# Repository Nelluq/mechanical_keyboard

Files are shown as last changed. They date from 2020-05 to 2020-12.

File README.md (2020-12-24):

# Mechanical Keyboard

## Background and Overview
This is a simple exposed-PCB design for a Cherry MX-based mechanical keyboard. It is a full-size 104-key board, but also
includes 4 extra keys that can be used for anything. It uses PCB-mount Cherry MX switches, and can be assembled with any
color non-backlit switch (I don't care for keyboard backlighting, so I didn't include it). It runs on an STM32F070C6
microcontroller.

The PCB was designed in [KiCad](https://kicad-pcb.org), which conveniently already had Cherry MX key switches in its
component libraries. Except for the key switches and the USB port, all the components are surface mount. This can make
it a little trickier to hand solder for people with less soldering experience (especially the 108 SOD-323 diodes...),
but it's entirely possible.

I started the project in August 2019 because I needed a better keyboard for work. I also wanted to try out STM32 MCUs,
which I hadn't used before. I couldn't get the firmware working initially, so set it aside for a few months and finally
finished it in February 2020. The first version of the firmware was written using the STM32Cube framework with
STM32 HAL, but I ended up not being satisfied with the generated code from that system, and the keyboard itself wasn't
working as well as I wanted. Eventually, in April 2020, I rewrote the entirity of the firmware using
[libopencm3](https://gitub.com/libopencm3/libopencm3), which is vastly cleaner and nicer to work with than ST's own
framework.

## Example
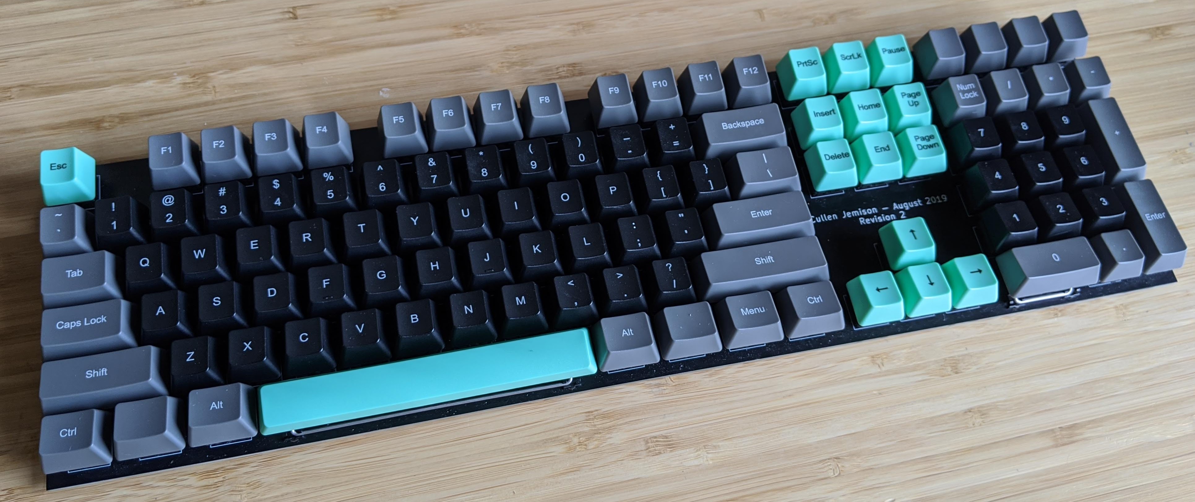
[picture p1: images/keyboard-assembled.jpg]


This is my keyboard, built on the Rev 2 PCB (newer PCB versions are slightly improved, but generally the same). I used
Cherry MX brown switches (I prefer blues, but I wanted this to be quieter for work) and opted for matte black
soldermask, which I think looks awesome.

## Instructions
Coming soon

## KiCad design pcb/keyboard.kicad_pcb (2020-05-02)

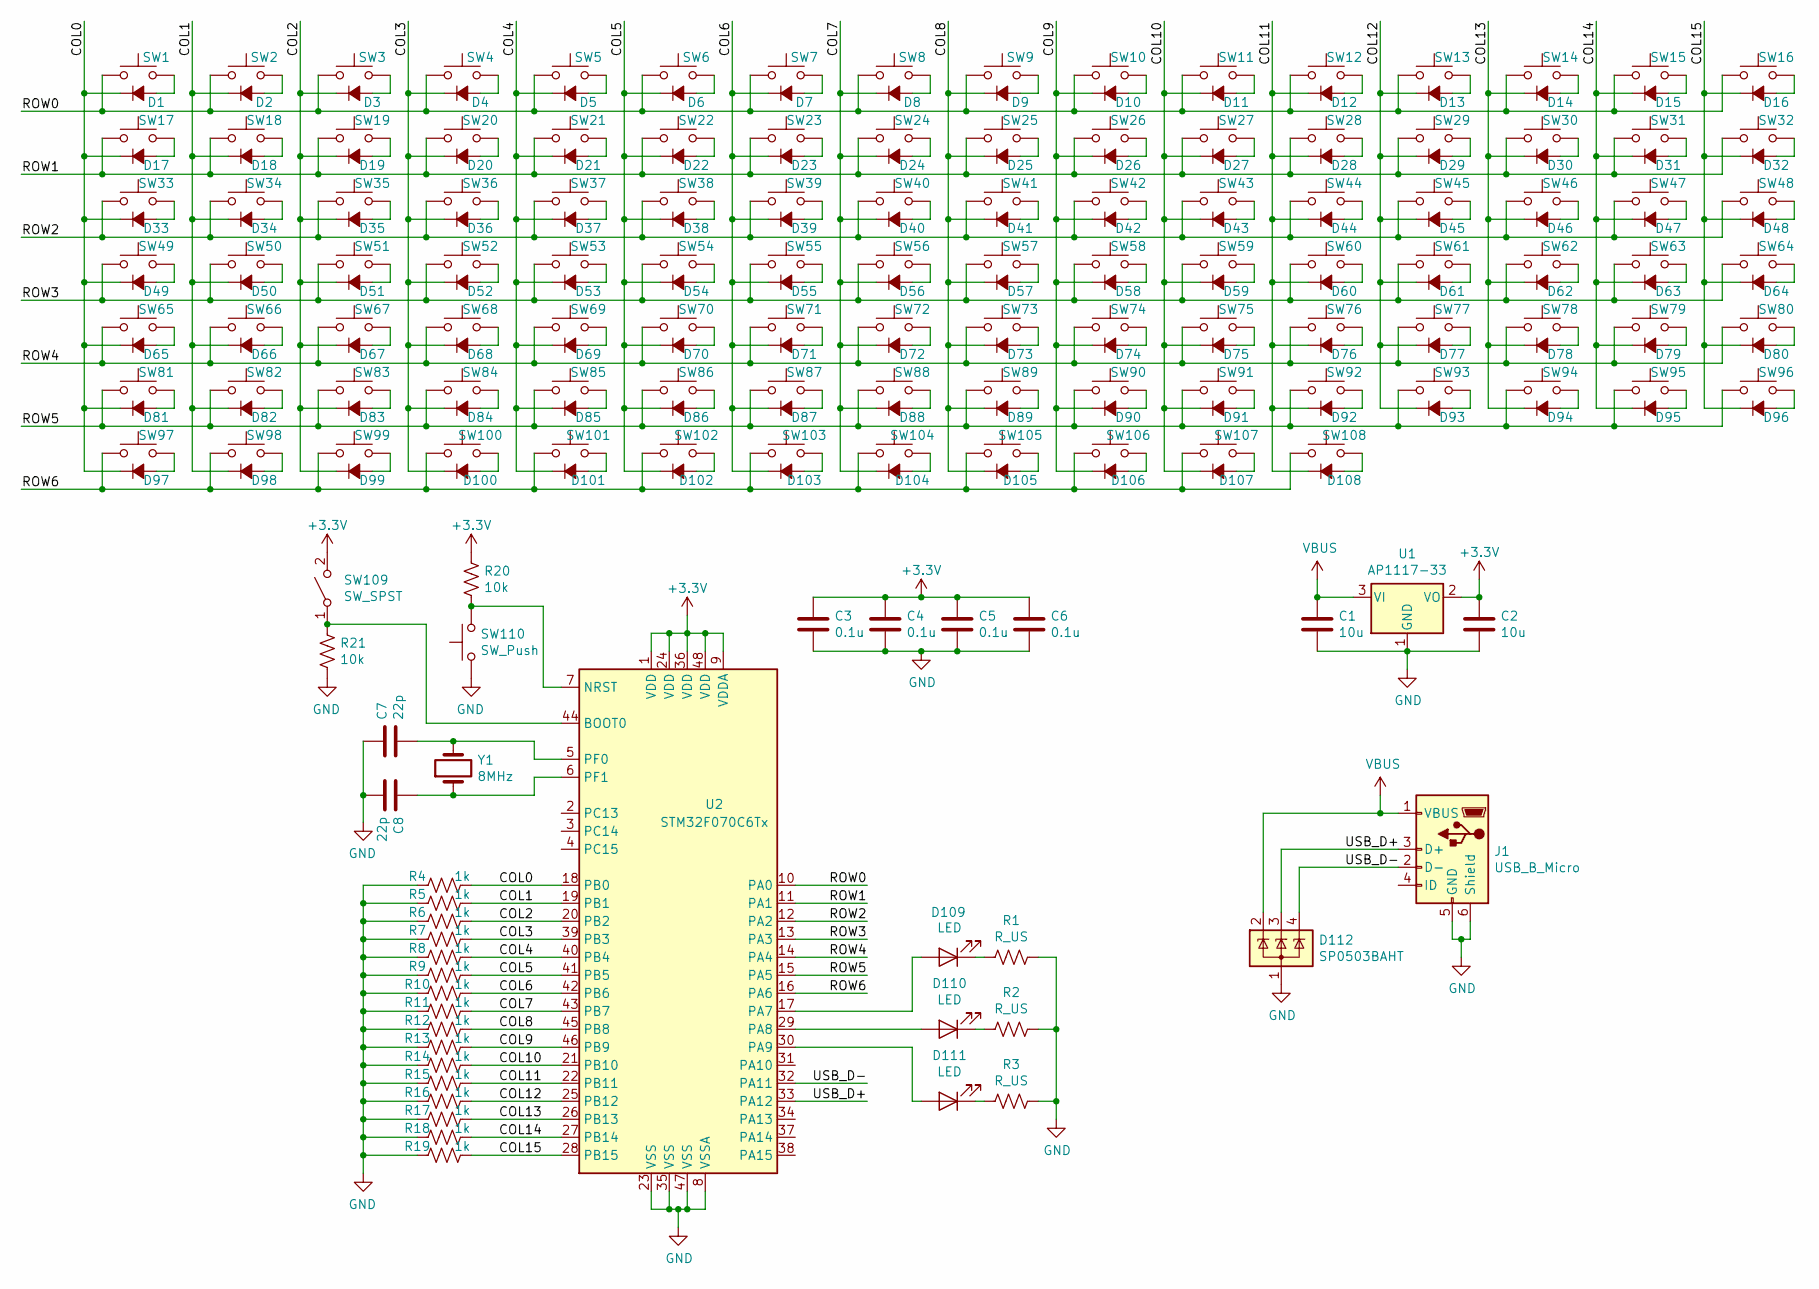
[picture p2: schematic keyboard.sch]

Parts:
C1, C2: 10u; C_0603_1608Metric
C3, C4, C5, C6: 0.1u; C_0603_1608Metric
C7, C8: 22p; C_0603_1608Metric
D1, D2, D3, D4, D5, D6, D7, D8, D9, D10, D11, D12, D13, D14, D15, D16, D17, D18, D19, D20, D21, D22, D23, D24, D25, D26, D27, D28, D29, D30, D31, D32, D33, D34, D35, D36, D37, D38, D39, D40, D41, D42, D43, D44, D45, D46, D47, D48, D49, D50, D51, D52, D53, D54, D55, D56, D57, D58, D59, D60, D61, D62, D63, D64, D65, D66, D67, D68, D69, D70, D71, D72, D73, D74, D75, D76, D77, D78, D79, D80, D81, D82, D83, D84, D85, D86, D87, D88, D89, D90, D91, D92, D93, D94, D95, D96, D97, D98, D99, D100, D101, D102, D103, D104, D105, D106, D107, D108: D_Small_ALT; D_0603_1608Metric
D109, D110, D111: LED; LED_0603_1608Metric
D112: SP0503BAHT; SOT-143
J1: USB_B_Micro; USB_Micro-B_Amphenol_10103594-0001LF_Horizontal
R1, R2, R3: R_US; R_0603_1608Metric
R4, R5, R6, R7, R8, R9, R10, R11, R12, R13, R14, R15, R16, R17, R18, R19: 1k; R_0603_1608Metric
R20, R21: 10k; R_0603_1608Metric
SW1, SW2, SW3, SW4, SW5, SW6, SW7, SW8, SW9, SW10, SW11, SW12, SW13, SW15, SW16, SW18, SW19, SW20, SW21, SW22, SW23, SW24, SW25, SW26, SW27, SW28, SW29, SW31, SW32, SW34, SW35, SW36, SW37, SW38, SW39, SW40, SW41, SW42, SW43, SW44, SW46, SW47, SW48, SW50, SW51, SW52, SW53, SW54, SW55, SW56, SW57, SW58, SW59, SW61, SW62, SW63, SW64, SW73, SW74, SW75, SW76, SW77, SW78, SW79, SW80, SW81, SW82, SW83, SW84, SW85, SW86, SW87, SW89, SW90, SW91, SW92, SW93, SW94, SW97, SW98, SW99, SW100, SW101, SW102, SW103, SW104, SW105, SW106, SW107, SW108: SW_Push; SW_Cherry_MX_1.00u_PCB
SW14, SW96: SW_Push; SW_Cherry_MX_2.00u_PCB
SW17, SW30: SW_Push; SW_Cherry_MX_1.50u_PCB
SW33: SW_Push; SW_Cherry_MX_1.75u_PCB
SW45, SW49: SW_Push; SW_Cherry_MX_2.25u_PCB
SW60: SW_Push; SW_Cherry_MX_2.75u_PCB
SW65, SW66, SW67, SW69, SW70, SW71, SW72: SW_Push; SW_Cherry_MX_1.25u_PCB
SW68: SW_Push; SW_Cherry_MX_6.25u_PCB
SW88, SW95: SW_Push; SW_Cherry_MX_2.00u_Vertical_PCB
SW109: SW_SPST; SW_SPST_PTS645
SW110: SW_Push; SW_SPST_PTS645
U1: AP1117-33; SOT-223-3_TabPin2
U2: STM32F070C6Tx; LQFP-48_7x7mm_P0.5mm
Y1: 8MHz; Crystal_SMD_HC49-SD

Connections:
+3V3: C2.1, C3.1, C4.1, C5.1, C6.1, R20.1, SW109.2 (B), U1.2 (VO), U2.1 (VDD), U2.9 (VDDA), U2.24 (VDD), U2.36 (VDD), U2.48 (VDD)
/COL0: D1.1 (K), D17.1 (K), D33.1 (K), D49.1 (K), D65.1 (K), D81.1 (K), D97.1 (K), R4.1, U2.18 (PB0)
/COL1: D2.1 (K), D18.1 (K), D34.1 (K), D50.1 (K), D66.1 (K), D82.1 (K), D98.1 (K), R5.1, U2.19 (PB1)
/COL2: D3.1 (K), D19.1 (K), D35.1 (K), D51.1 (K), D67.1 (K), D83.1 (K), D99.1 (K), R6.1, U2.20 (PB2)
/COL3: D4.1 (K), D20.1 (K), D36.1 (K), D52.1 (K), D68.1 (K), D84.1 (K), D100.1 (K), R7.1, U2.39 (PB3)
/COL4: D5.1 (K), D21.1 (K), D37.1 (K), D53.1 (K), D69.1 (K), D85.1 (K), D101.1 (K), R8.1, U2.40 (PB4)
/COL5: D6.1 (K), D22.1 (K), D38.1 (K), D54.1 (K), D70.1 (K), D86.1 (K), D102.1 (K), R9.1, U2.41 (PB5)
/COL6: D7.1 (K), D23.1 (K), D39.1 (K), D55.1 (K), D71.1 (K), D87.1 (K), D103.1 (K), R10.1, U2.42 (PB6)
/COL7: D8.1 (K), D24.1 (K), D40.1 (K), D56.1 (K), D72.1 (K), D88.1 (K), D104.1 (K), R11.1, U2.43 (PB7)
/COL8: D9.1 (K), D25.1 (K), D41.1 (K), D57.1 (K), D73.1 (K), D89.1 (K), D105.1 (K), R12.1, U2.45 (PB8)
/COL9: D10.1 (K), D26.1 (K), D42.1 (K), D58.1 (K), D74.1 (K), D90.1 (K), D106.1 (K), R13.1, U2.46 (PB9)
/COL10: D11.1 (K), D27.1 (K), D43.1 (K), D59.1 (K), D75.1 (K), D91.1 (K), D107.1 (K), R14.1, U2.21 (PB10)
/COL11: D12.1 (K), D28.1 (K), D44.1 (K), D60.1 (K), D76.1 (K), D92.1 (K), D108.1 (K), R15.1, U2.22 (PB11)
/COL12: D13.1 (K), D29.1 (K), D45.1 (K), D61.1 (K), D77.1 (K), D93.1 (K), R16.1, U2.25 (PB12)
/COL13: D14.1 (K), D30.1 (K), D46.1 (K), D62.1 (K), D78.1 (K), D94.1 (K), R17.1, U2.26 (PB13)
/COL14: D15.1 (K), D31.1 (K), D47.1 (K), D63.1 (K), D79.1 (K), D95.1 (K), R18.1, U2.27 (PB14)
/COL15: D16.1 (K), D32.1 (K), D48.1 (K), D64.1 (K), D80.1 (K), D96.1 (K), R19.1, U2.28 (PB15)
/ROW0: SW1.1, SW2.1, SW3.1, SW4.1, SW5.1, SW6.1, SW7.1, SW8.1, SW9.1, SW10.1, SW11.1, SW12.1, SW13.1, SW14.1, SW15.1, SW16.1, U2.10 (PA0)
/ROW1: SW17.1, SW18.1, SW19.1, SW20.1, SW21.1, SW22.1, SW23.1, SW24.1, SW25.1, SW26.1, SW27.1, SW28.1, SW29.1, SW30.1, SW31.1, SW32.1, U2.11 (PA1)
/ROW2: SW33.1, SW34.1, SW35.1, SW36.1, SW37.1, SW38.1, SW39.1, SW40.1, SW41.1, SW42.1, SW43.1, SW44.1, SW45.1, SW46.1, SW47.1, SW48.1, U2.12 (PA2)
/ROW3: SW49.1, SW50.1, SW51.1, SW52.1, SW53.1, SW54.1, SW55.1, SW56.1, SW57.1, SW58.1, SW59.1, SW60.1, SW61.1, SW62.1, SW63.1, SW64.1, U2.13 (PA3)
/ROW4: SW65.1, SW66.1, SW67.1, SW68.1, SW69.1, SW70.1, SW71.1, SW72.1, SW73.1, SW74.1, SW75.1, SW76.1, SW77.1, SW78.1, SW79.1, SW80.1, U2.14 (PA4)
/ROW5: SW81.1, SW82.1, SW83.1, SW84.1, SW85.1, SW86.1, SW87.1, SW88.1, SW89.1, SW90.1, SW91.1, SW92.1, SW93.1, SW94.1, SW95.1, SW96.1, U2.15 (PA5)
/ROW6: SW97.1, SW98.1, SW99.1, SW100.1, SW101.1, SW102.1, SW103.1, SW104.1, SW105.1, SW106.1, SW107.1, SW108.1, U2.16 (PA6)
/USB_D+: D112.3 (K), J1.3 (D+), U2.33 (PA12)
/USB_D-: D112.4 (K), J1.2 (D-), U2.32 (PA11)
GND: C1.2, C2.2, C3.2, C4.2, C5.2, C6.2, C7.1, C8.2, D112.1 (A), J1.5 (GND), J1.6 (Shield), R1.1, R2.1, R3.1, R4.2, R5.2, R6.2, R7.2, R8.2, R9.2, R10.2, R11.2, R12.2, R13.2, R14.2, R15.2, R16.2, R17.2, R18.2, R19.2, R21.2, SW110.2, U1.1 (GND), U2.8 (VSSA), U2.23 (VSS), U2.35 (VSS), U2.47 (VSS)
unnamed: C7.2, U2.5 (PF0), Y1.2
unnamed: C8.1, U2.6 (PF1), Y1.1
unnamed: D1.2 (A), SW1.2
unnamed: D2.2 (A), SW2.2
unnamed: D3.2 (A), SW3.2
unnamed: D4.2 (A), SW4.2
unnamed: D5.2 (A), SW5.2
unnamed: D6.2 (A), SW6.2
unnamed: D7.2 (A), SW7.2
unnamed: D8.2 (A), SW8.2
unnamed: D9.2 (A), SW9.2
unnamed: D10.2 (A), SW10.2
unnamed: D11.2 (A), SW11.2
unnamed: D12.2 (A), SW12.2
unnamed: D13.2 (A), SW13.2
unnamed: D14.2 (A), SW14.2
unnamed: D15.2 (A), SW15.2
unnamed: D16.2 (A), SW16.2
unnamed: D17.2 (A), SW17.2
unnamed: D18.2 (A), SW18.2
unnamed: D19.2 (A), SW19.2
unnamed: D20.2 (A), SW20.2
unnamed: D21.2 (A), SW21.2
unnamed: D22.2 (A), SW22.2
unnamed: D23.2 (A), SW23.2
unnamed: D24.2 (A), SW24.2
unnamed: D25.2 (A), SW25.2
unnamed: D26.2 (A), SW26.2
unnamed: D27.2 (A), SW27.2
unnamed: D28.2 (A), SW28.2
unnamed: D29.2 (A), SW29.2
unnamed: D30.2 (A), SW30.2
unnamed: D31.2 (A), SW31.2
unnamed: D32.2 (A), SW32.2
unnamed: D33.2 (A), SW33.2
unnamed: D34.2 (A), SW34.2
unnamed: D35.2 (A), SW35.2
unnamed: D36.2 (A), SW36.2
unnamed: D37.2 (A), SW37.2
unnamed: D38.2 (A), SW38.2
unnamed: D39.2 (A), SW39.2
unnamed: D40.2 (A), SW40.2
unnamed: D41.2 (A), SW41.2
unnamed: D42.2 (A), SW42.2
unnamed: D43.2 (A), SW43.2
unnamed: D44.2 (A), SW44.2
unnamed: D45.2 (A), SW45.2
unnamed: D46.2 (A), SW46.2
unnamed: D47.2 (A), SW47.2
unnamed: D48.2 (A), SW48.2
unnamed: D49.2 (A), SW49.2
unnamed: D50.2 (A), SW50.2
unnamed: D51.2 (A), SW51.2
unnamed: D52.2 (A), SW52.2
unnamed: D53.2 (A), SW53.2
unnamed: D54.2 (A), SW54.2
unnamed: D55.2 (A), SW55.2
unnamed: D56.2 (A), SW56.2
unnamed: D57.2 (A), SW57.2
unnamed: D58.2 (A), SW58.2
unnamed: D59.2 (A), SW59.2
unnamed: D60.2 (A), SW60.2
unnamed: D61.2 (A), SW61.2
unnamed: D62.2 (A), SW62.2
unnamed: D63.2 (A), SW63.2
unnamed: D64.2 (A), SW64.2
unnamed: D65.2 (A), SW65.2
unnamed: D66.2 (A), SW66.2
unnamed: D67.2 (A), SW67.2
unnamed: D68.2 (A), SW68.2
unnamed: D69.2 (A), SW69.2
unnamed: D70.2 (A), SW70.2
unnamed: D71.2 (A), SW71.2
unnamed: D72.2 (A), SW72.2
unnamed: D73.2 (A), SW73.2
unnamed: D74.2 (A), SW74.2
unnamed: D75.2 (A), SW75.2
unnamed: D76.2 (A), SW76.2
unnamed: D77.2 (A), SW77.2
unnamed: D78.2 (A), SW78.2
unnamed: D79.2 (A), SW79.2
unnamed: D80.2 (A), SW80.2
unnamed: D81.2 (A), SW81.2
unnamed: D82.2 (A), SW82.2
unnamed: D83.2 (A), SW83.2
unnamed: D84.2 (A), SW84.2
unnamed: D85.2 (A), SW85.2
unnamed: D86.2 (A), SW86.2
unnamed: D87.2 (A), SW87.2
unnamed: D88.2 (A), SW88.2
unnamed: D89.2 (A), SW89.2
unnamed: D90.2 (A), SW90.2
unnamed: D91.2 (A), SW91.2
unnamed: D92.2 (A), SW92.2
unnamed: D93.2 (A), SW93.2
unnamed: D94.2 (A), SW94.2
unnamed: D95.2 (A), SW95.2
unnamed: D96.2 (A), SW96.2
unnamed: D97.2 (A), SW97.2
unnamed: D98.2 (A), SW98.2
unnamed: D99.2 (A), SW99.2
unnamed: D100.2 (A), SW100.2
unnamed: D101.2 (A), SW101.2
unnamed: D102.2 (A), SW102.2
unnamed: D103.2 (A), SW103.2
unnamed: D104.2 (A), SW104.2
unnamed: D105.2 (A), SW105.2
unnamed: D106.2 (A), SW106.2
unnamed: D107.2 (A), SW107.2
unnamed: D108.2 (A), SW108.2
unnamed: D109.1 (K), R1.2
unnamed: D109.2 (A), U2.17 (PA7)
unnamed: D110.1 (K), R2.2
unnamed: D110.2 (A), U2.29 (PA8)
unnamed: D111.1 (K), R3.2
unnamed: D111.2 (A), U2.30 (PA9)
unnamed: R20.2, SW110.1, U2.7 (NRST)
unnamed: R21.1, SW109.1 (A), U2.44 (BOOT0)
VBUS: C1.1, D112.2 (K), J1.1 (VBUS), U1.3 (VI)

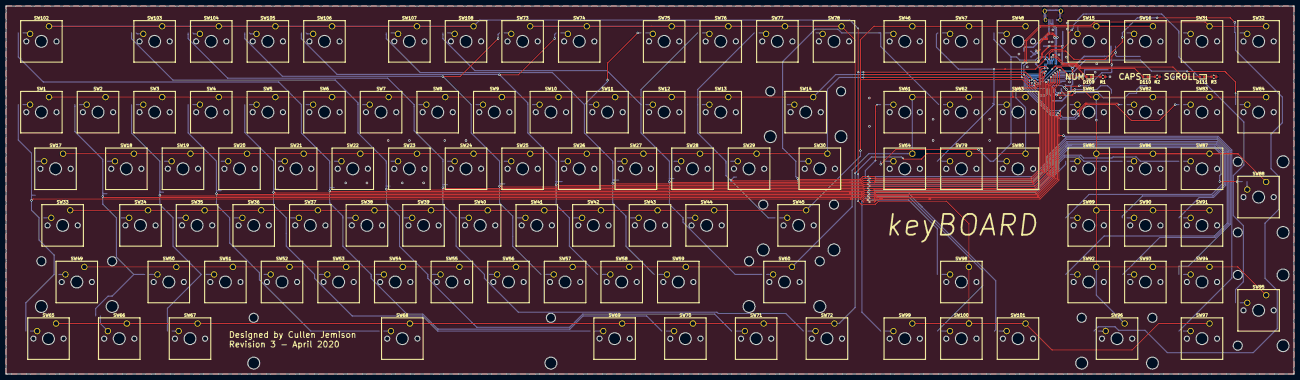
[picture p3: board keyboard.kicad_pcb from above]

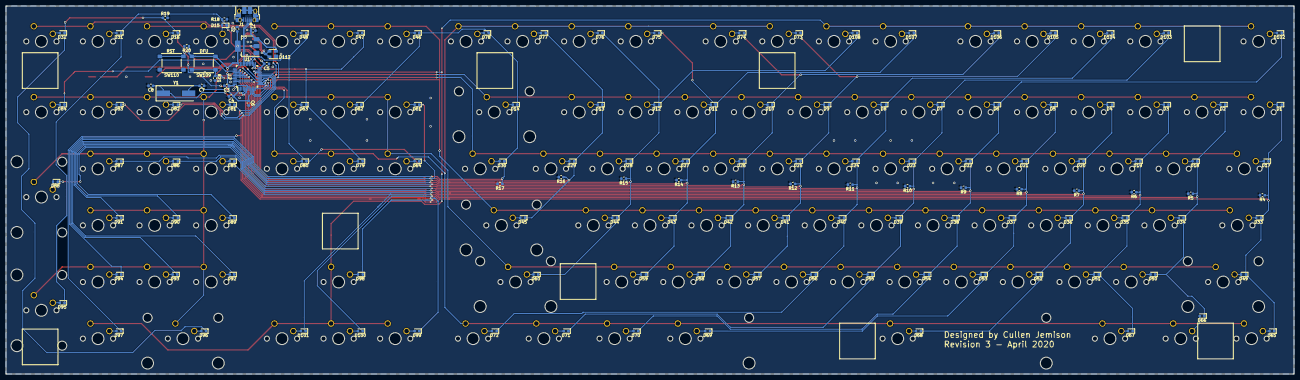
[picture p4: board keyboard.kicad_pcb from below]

Board: 2 copper layers, 433.4 x 123.8 mm, 255 parts (141 on the bottom side), 146 nets.

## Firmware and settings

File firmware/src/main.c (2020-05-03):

/**
 * MIT License
 * 
 * Copyright (c) 2020 Cullen Jemison
 * 
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
 * THE SOFTWARE IS PROVIDED "AS IS", WITHOUT WARRANTY OF ANY KIND, EXPRESS OR
 * IMPLIED, INCLUDING BUT NOT LIMITED TO THE WARRANTIES OF MERCHANTABILITY,
 * FITNESS FOR A PARTICULAR PURPOSE AND NONINFRINGEMENT. IN NO EVENT SHALL THE
 * AUTHORS OR COPYRIGHT HOLDERS BE LIABLE FOR ANY CLAIM, DAMAGES OR OTHER
 * LIABILITY, WHETHER IN AN ACTION OF CONTRACT, TORT OR OTHERWISE, ARISING FROM,
 * OUT OF OR IN CONNECTION WITH THE SOFTWARE OR THE USE OR OTHER DEALINGS IN THE
 * SOFTWARE.
 */

#include "keyboard.h"
#include "usb_hid.h"

#include <libopencm3/cm3/nvic.h>
#include <libopencm3/cm3/systick.h>
#include <libopencm3/stm32/flash.h>
#include <libopencm3/stm32/gpio.h>
#include <libopencm3/stm32/rcc.h>

static void setup_clock(void) {
    rcc_osc_on(RCC_HSE);
    rcc_wait_for_osc_ready(RCC_HSE);
    rcc_set_sysclk_source(RCC_HSE);

    rcc_set_hpre(RCC_CFGR_HPRE_NODIV);
    rcc_set_ppre(RCC_CFGR_PPRE_NODIV);

    flash_prefetch_enable();
    flash_set_ws(FLASH_ACR_LATENCY_024_048MHZ);

    // set PLL for 48MHz (12MHz HSI * 4 = 48MHz)
    rcc_set_pll_multiplication_factor(RCC_CFGR_PLLMUL_MUL4);
    rcc_set_pll_source(RCC_CFGR_PLLSRC_HSE_CLK);
    rcc_set_pllxtpre(RCC_CFGR_PLLXTPRE_HSE_CLK);

    rcc_osc_on(RCC_PLL);
    rcc_wait_for_osc_ready(RCC_PLL);
    rcc_set_sysclk_source(RCC_PLL);

    rcc_apb1_frequency = 48000000;
    rcc_ahb_frequency = 48000000;

    systick_set_clocksource(STK_CSR_CLKSOURCE_EXT);
    systick_set_frequency(1000 / KEYBOARD_POLL_INTERVAL_MS, rcc_ahb_frequency);
    systick_counter_enable();
    systick_interrupt_enable();
}

void sys_tick_handler(void) {
    keyboard_poll();
}

int main(void) {
    setup_clock();
    usb_hid_init();
    keyboard_init();

    while(1) {
        usb_hid_poll();
    }
}

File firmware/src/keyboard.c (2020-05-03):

/**
 * MIT License
 * 
 * Copyright (c) 2020 Cullen Jemison
 * 
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
 * THE SOFTWARE IS PROVIDED "AS IS", WITHOUT WARRANTY OF ANY KIND, EXPRESS OR
 * IMPLIED, INCLUDING BUT NOT LIMITED TO THE WARRANTIES OF MERCHANTABILITY,
 * FITNESS FOR A PARTICULAR PURPOSE AND NONINFRINGEMENT. IN NO EVENT SHALL THE
 * AUTHORS OR COPYRIGHT HOLDERS BE LIABLE FOR ANY CLAIM, DAMAGES OR OTHER
 * LIABILITY, WHETHER IN AN ACTION OF CONTRACT, TORT OR OTHERWISE, ARISING FROM,
 * OUT OF OR IN CONNECTION WITH THE SOFTWARE OR THE USE OR OTHER DEALINGS IN THE
 * SOFTWARE.
 */

#include "keyboard.h"
#include "flash_store.h"
#include "hid_codes.h"
#include "usb_hid.h"

#include <string.h>

#include <libopencm3/stm32/gpio.h>
#include <libopencm3/stm32/rcc.h>

#define ROW_GPIO_PORT GPIOA
#define COL_GPIO_PORT GPIOB

#define ROW_START_PIN 0
#define COL_START_PIN 0

#define NUM_ROWS (uint16_t)7
#define NUM_COLS (uint16_t)16

#define NUMLK_LED_PORT GPIOA
#define NUMLK_LED_PIN GPIO7

#define CAPLK_LED_PORT GPIOA
#define CAPLK_LED_PIN GPIO8

#define SCRLK_LED_PORT GPIOA
#define SCRLK_LED_PIN GPIO9

#define HID_LED_NUMLK 0x1
#define HID_LED_CAPLK 0x2
#define HID_LED_SCRLK 0x4

#define LED_SELF_TEST_PERIOD_MS 1000
#define LED_SELF_TEST_CYCLES (LED_SELF_TEST_PERIOD_MS / KEYBOARD_POLL_INTERVAL_MS)

#define MACRO_FLASH_STORE_ADDR 0
#define NUM_MACROS 4

enum keyboard_led {
    KB_LED_NUMLK,
    KB_LED_CAPLK,
    KB_LED_SCRLK,
};

// mapping of (row, column) to key code
static const uint8_t keyboard_key_map[NUM_ROWS][NUM_COLS] = {
    {KEY_GRAVE, KEY_1, KEY_2, KEY_3, KEY_4, KEY_5, KEY_6, KEY_7, KEY_8, KEY_9, KEY_0, KEY_MINUS, KEY_EQUAL, KEY_BACKSPACE, 0, 0},
    {KEY_TAB, KEY_Q, KEY_W, KEY_E, KEY_R, KEY_T, KEY_Y, KEY_U, KEY_I, KEY_O, KEY_P, KEY_LEFTBRACE, KEY_RIGHTBRACE, KEY_BACKSLASH, 0, 0},
    {KEY_CAPSLOCK, KEY_A, KEY_S, KEY_D, KEY_F, KEY_G, KEY_H, KEY_J, KEY_K, KEY_L, KEY_SEMICOLON, KEY_APOSTROPHE, KEY_ENTER, KEY_SYSRQ, KEY_SCROLLLOCK, KEY_PAUSE},
    {0, KEY_Z, KEY_X, KEY_C, KEY_V, KEY_B, KEY_N, KEY_M, KEY_COMMA, KEY_DOT, KEY_SLASH, 0, KEY_INSERT, KEY_HOME, KEY_PAGEUP, KEY_DELETE},
    {0, 0, 0, KEY_SPACE, 0, 0, KEY_PROPS, 0, KEY_F7, KEY_F8, KEY_F9, KEY_F10, KEY_F11, KEY_F12, KEY_END, KEY_PAGEDOWN},
    {KEY_NUMLOCK, KEY_KPSLASH, KEY_KPASTERISK, KEY_KPMINUS, KEY_KP7, KEY_KP8, KEY_KP9, KEY_KPPLUS, KEY_KP4, KEY_KP5, KEY_KP6, KEY_KP1, KEY_KP2, KEY_KP3, KEY_KPENTER, KEY_KP0},
    {KEY_KPDOT, KEY_UP, KEY_LEFT, KEY_DOWN, KEY_RIGHT, KEY_ESC, KEY_F1, KEY_F2, KEY_F3, KEY_F4, KEY_F5, KEY_F6, 0, 0, 0, 0},
};

// mapping of (row, column) to modifier
static const uint8_t keyboard_modifier_map[NUM_ROWS][NUM_COLS] = {
    {0, 0, 0, 0, 0, 0, 0, 0, 0, 0, 0, 0, 0, 0, 0, 0},
    {0, 0, 0, 0, 0, 0, 0, 0, 0, 0, 0, 0, 0, 0, 0, 0},
    {0, 0, 0, 0, 0, 0, 0, 0, 0, 0, 0, 0, 0, 0, 0, 0},
    {KEY_MOD_LSHIFT, 0, 0, 0, 0, 0, 0, 0, 0, 0, 0, KEY_MOD_RSHIFT, 0, 0, 0, 0},
    {KEY_MOD_LCTRL, KEY_MOD_LMETA, KEY_MOD_LALT, 0, KEY_MOD_RALT, KEY_MOD_RMETA, 0, KEY_MOD_RCTRL, 0, 0, 0, 0, 0, 0, 0, 0},
    {0, 0, 0, 0, 0, 0, 0, 0, 0, 0, 0, 0, 0, 0, 0, 0},
    {0, 0, 0, 0, 0, 0, 0, 0, 0, 0, 0, 0, 0, 0, 0, 0},
};

static uint8_t keyboard_key_pressed[NUM_ROWS][NUM_COLS] = {0};

struct keyboard_macro_key {
    uint8_t row;
    uint8_t col;
    uint8_t key_code;
};

static struct keyboard_macro_key keyboard_macros[NUM_MACROS] = {
    {.row = 0, .col = 14, .key_code = KEY_A},
    {.row = 0, .col = 15, .key_code = KEY_S},
    {.row = 1, .col = 14, .key_code = KEY_D},
    {.row = 1, .col = 15, .key_code = KEY_F},
};

static uint16_t keyboard_poll_row = 0;

static struct usb_hid_report keyboard_hid_report;

static bool keyboard_data_updated = false;
static bool keyboard_overflow = false;

static uint32_t keyboard_led_self_test_counter = 0;
static bool keyboard_led_self_test_done = false;

static void add_key(uint8_t key_code) {
    // don't bother trying if this key doesn't have a key code (i.e. it's a modifier key)
    if (key_code == KEY_NONE) {
        return;
    }
    
    int free_slot = -1;
    for (int slot = 0; slot < MAX_NUM_KEY_CODES; slot++) {
        // do not add a key multiple times
        if (keyboard_hid_report.key_codes[slot] == key_code) {
            return;
        }

        // find the next free slot, add the key code
        if (keyboard_hid_report.key_codes[slot] == KEY_NONE) {
            free_slot = slot;
        }
    }

    if (free_slot != -1) {
        keyboard_hid_report.key_codes[free_slot] = key_code;
        keyboard_data_updated = true;
    } else {
        // overflow - indicate this to the host
        keyboard_overflow = true;
    }
}
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

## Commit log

2020-05-02 Added PCB
    [keyboard.kicad_pcb, keyboard.sch]
2020-05-03 [#1] Added support for LED lock status indicators
